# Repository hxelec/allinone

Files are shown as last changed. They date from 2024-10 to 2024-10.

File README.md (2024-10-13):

KiCad files for BIG DECK all-in-one controller.
I would strongly recommend AGAINST going out and manufacturing this board because of the faulty reverse polarity protection circuit, which blocks reverse current, reducing reliability when the motors brake and try to return energy to the battery.
These files are only meant as a reference for people to learn from.
Thank you so much for your support :)
Ask me questions on the related video on my YouTube channel, I might not see them if you ask here on GitHub.

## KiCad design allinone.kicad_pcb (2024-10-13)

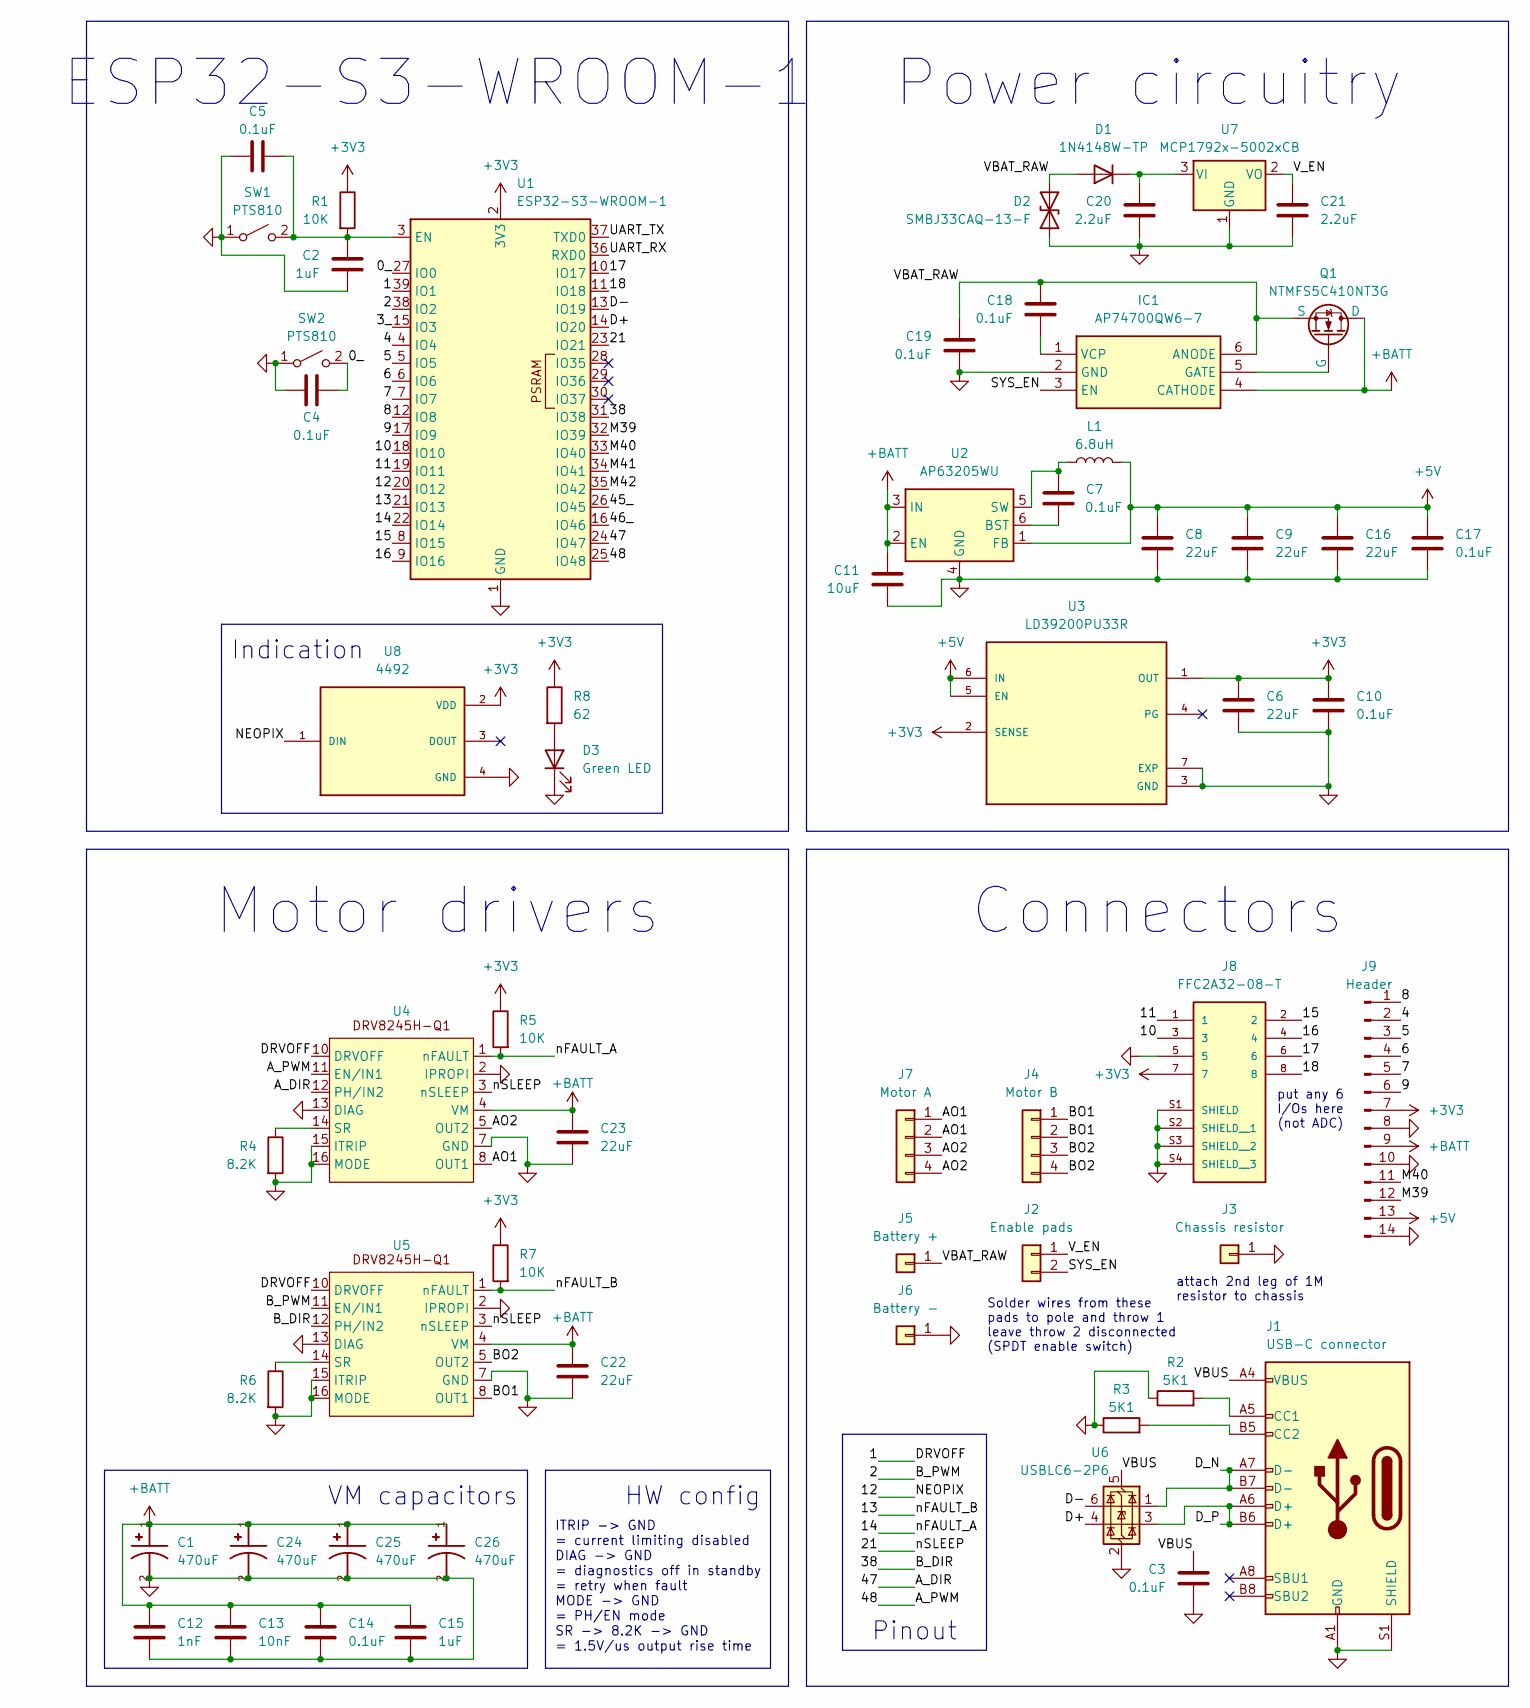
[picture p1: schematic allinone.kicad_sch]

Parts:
C1, C24, C25, C26: 470uF; CP_Radial_D8.0mm_P3.50mm; MPN EEU-FR1V471LB
C2, C15: 1uF; C_0402_1005Metric; MPN GRM155R6YA105KE11D
C3, C4, C5, C7, C10, C14, C17, C18, C19: 0.1uF; C_0402_1005Metric; MPN CGA2B3X7R1V104K050BB
C6, C8, C9, C16: 22uF; C_0603_1608Metric; MPN CL10A226MP8NUNE
C11: 10uF; C_0805_2012Metric; MPN GRM21BR6YA106ME43L
C12: 1nF; C_0402_1005Metric; MPN GRM1555C1H102JA01D
C13: 10nF; C_0402_1005Metric; MPN CGA2B3X7R1V103K050BB
C20, C21: 2.2uF; C_0603_1608Metric; MPN GRT188R61H225KE13D
C22, C23: 22uF; C_1206_3216Metric; MPN GMC31X5R226M35NT
D1: 1N4148W-TP; D_SOD-123; MPN 1N4148W-TP
D2: SMBJ33CAQ-13-F; D_SMB; MPN SMBJ33CAQ-13-F
D3: Green LED; LED_0805_2012Metric; MPN B1701UYG-20D000114U1930
IC1: AP74700QW6-7; SOT95P285X140-6N; MPN AP74700QW6-7
J1: USB-C connector; USB_C_Receptacle_GCT_USB4105-xx-A_16P_TopMnt_Horizontal; MPN USB4105-GF-A
J2: Enable pads; PinHeader_1x02_P2.54mm_Vertical
J3: Chassis resistor; SolderWire-0.5sqmm_1x01_D0.9mm_OD2.1mm
J4: Motor B; Motor pads 10A
J5: Battery +; Battery pads 30A
J6: Battery -; Battery pads 30A
J7: Motor A; Motor pads 10A
J8: FFC2A32-08-T; GCT_FFC2A32-08-T; PARTREV 0.1
J9: Header; PinHeader_1x14_P2.54mm_Vertical
L1: 6.8uH; L_Bourns_SRN6045TA; MPN SRN6045TA-4R7M
Q1: NTMFS5C410NT3G; ONSemi_SO-8FL_488AA; MPN NTMFS5C410NT3G
R1, R5, R7: 10K; R_0402_1005Metric; MPN RC0402JR-0710KL
R2, R3: 5K1; R_0402_1005Metric; MPN RC0402FR-075K1L
R4, R6: 8.2K; R_0402_1005Metric; MPN RC0402FR-078K2L
R8: 62; R_0402_1005Metric; MPN RC0402JR-0762RL
SW1, SW2: PTS810; SW_SPST_PTS810; MPN PTS810 SJK 250 SMTR LFS
U1: ESP32-S3-WROOM-1; MPN ESP32-S3-WROOM-1-N16R8
U2: AP63205WU; TSOT-23-6; MPN AP63205WU-7
U3: LD39200PU33R; SON95P300X300X100-7N-D; MPN LD39200PU33R
U4, U5: DRV8245H-Q1; MPN DRV8245HQRXZRQ1
U6: USBLC6-2P6; SOT-666; MPN USBLC6-2P6
U7: MCP1792x-5002xCB; SOT-23; MPN MCP1792T-5002H/CB
U8: 4492; LED_4492; MPN 4492

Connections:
+3V3: C6.1, C10.1, J8.7, J9.7, R1.1, R5.1, R7.1, R8.1, U1.2 (3V3), U3.1 (OUT), U3.2 (SENSE), U8.2 (VDD)
+5V: C8.1, C9.1, C16.1, C17.2, J9.13, L1.2, U2.1 (FB), U3.5 (EN), U3.6 (IN)
+BATT: C1.1, C11.1, C12.2, C13.2, C14.2, C15.2, C22.1, C23.1, C24.1, C25.1, C26.1, IC1.4 (CATHODE), J9.9, Q1.5 (D), Q1.6 (D), U2.2 (EN), U2.3 (IN), U4.4 (VM), U5.4 (VM)
/0_: C4.2, SW2.2 (B), U1.27 (IO0)
/1: U1.39 (IO1), U4.10 (DRVOFF), U5.10 (DRVOFF)
/2: U1.38 (IO2), U5.11 (EN/IN1)
/3_: U1.15 (IO3)
/4: J9.2, U1.4 (IO4)
/5: J9.3, U1.5 (IO5)
/6: J9.4, U1.6 (IO6)
/7: J9.5, U1.7 (IO7)
/8: J9.1, U1.12 (IO8)
/9: J9.6, U1.17 (IO9)
/10: J8.3, U1.18 (IO10)
/11: J8.1, U1.19 (IO11)
/12: U1.20 (IO12), U8.1 (DIN)
/13: R7.2, U1.21 (IO13), U5.1 (nFAULT)
/14: R5.2, U1.22 (IO14), U4.1 (nFAULT)
/15: J8.2, U1.8 (IO15)
/16: J8.4, U1.9 (IO16)
/17: J8.6, U1.10 (IO17)
/18: J8.8, U1.11 (IO18)
/21: U1.23 (IO21), U4.3 (nSLEEP), U5.3 (nSLEEP)
/38: U1.31 (IO38), U5.12 (PH/IN2)
/45_: U1.26 (IO45)
/46_: U1.16 (IO46)
/47: U1.24 (IO47), U4.12 (PH/IN2)
/48: U1.25 (IO48), U4.11 (EN/IN1)
/AO1: J7.1, J7.2, U4.8 (OUT1), U4.9 (OUT1)
/AO2: J7.3, J7.4, U4.5 (OUT2), U4.6 (OUT2)
/BO1: J4.1, J4.2, U5.8 (OUT1), U5.9 (OUT1)
/BO2: J4.3, J4.4, U5.5 (OUT2), U5.6 (OUT2)
/D+: U1.14 (IO20), U6.4 (I/O2)
/D-: U1.13 (IO19), U6.6 (I/O1)
/D_N: J1.A7 (D-), J1.B7 (D-), U6.1 (I/O1)
/D_P: J1.A6 (D+), J1.B6 (D+), U6.3 (I/O2)
/M39: J9.12, U1.32 (IO39)
/M40: J9.11, U1.33 (IO40)
/M41: U1.34 (IO41)
/M42: U1.35 (IO42)
/SYS_EN: IC1.3 (EN), J2.2
/UART_RX: U1.36 (RXD0)
/UART_TX: U1.37 (TXD0)
/VBAT_RAW: C18.2, C19.2, D1.2 (A), D2.2 (A2), IC1.6 (ANODE), J5.1, Q1.1 (S), Q1.2 (S), Q1.3 (S)
/VBUS: C3.1, J1.A4 (VBUS), J1.A9 (VBUS), J1.B4 (VBUS), J1.B9 (VBUS), U6.5 (VBUS)
/V_EN: C21.2, J2.1, U7.2 (VO)
GND: C1.2, C2.2, C3.2, C4.1, C5.2, C6.2, C8.2, C9.2, C10.2, C11.2, C12.1, C13.1, C14.1, C15.1, C16.2, C17.1, C19.1, C20.1, C21.1, C22.2, C23.2, C24.2, C25.2, C26.2, D2.1 (A1), D3.1 (K), IC1.2 (GND), J1.A1 (GND), J1.A12 (GND), J1.B1 (GND), J1.B12 (GND), J1.S1 (SHIELD), J3.1, J6.1, J8.5, J8.S1 (SHIELD), J8.S2 (SHIELD__1), J8.S3 (SHIELD__2), J8.S4 (SHIELD__3), J9.8, J9.10, J9.14, R2.1, R3.1, R4.2, R6.2, SW1.1 (A), SW2.1 (A), U1.1 (GND), U1.40 (GND), U1.41 (GND), U2.4 (GND), U3.3 (GND), U3.7 (EXP), U4.2 (IPROPI), U4.7 (GND), U4.13 (DIAG), U4.15 (ITRIP), U4.16 (MODE), U5.2 (IPROPI), U5.7 (GND), U5.13 (DIAG), U5.15 (ITRIP), U5.16 (MODE), U6.2 (GND), U7.1 (GND), U8.4 (GND)
unnamed: C20.2, D1.1 (K), U7.3 (VI)
unnamed: D3.2 (A), R8.2
unnamed: IC1.5 (GATE), Q1.4 (G)
unnamed: C18.1, IC1.1 (VCP)
unnamed: J1.A5 (CC1), R2.2
unnamed: J1.B5 (CC2), R3.2
unnamed: C2.1, C5.1, R1.2, SW1.2 (B), U1.3 (EN)
unnamed: C7.1, U2.6 (BST)
unnamed: C7.2, L1.1, U2.5 (SW)
unnamed: R4.1, U4.14 (SR)
unnamed: R6.1, U5.14 (SR)

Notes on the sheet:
Indication
ITRIP -> GND = current limiting disabled DIAG -> GND = diagnostics off in standby = retry when fault MODE -> GND = PH/EN mode SR -> 8.2K -> GND = 1.5V/us output rise time
ESP32-S3-WROOM-1
Motor drivers
Power circuitry
Connectors
Solder wires from these pads to pole and throw 1 leave throw 2 disconnected (SPDT enable switch)
put any 6 I/Os here (not ADC)
VM capacitors
HW config
Pinout
attach 2nd leg of 1M resistor to chassis

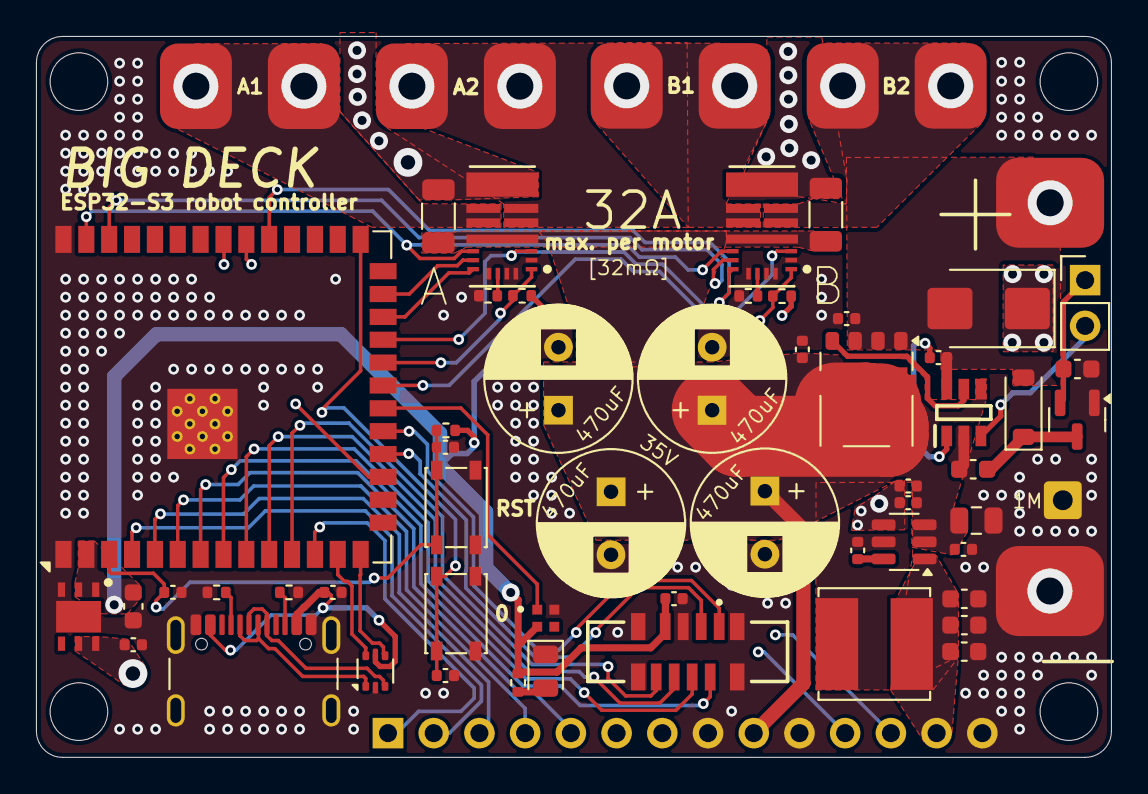
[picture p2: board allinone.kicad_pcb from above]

Board: 4 copper layers, 59.7 x 40.0 mm, 59 parts (1 on the bottom side), 51 nets.
